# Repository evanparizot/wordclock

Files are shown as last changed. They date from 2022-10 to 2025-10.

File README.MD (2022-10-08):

# WordClock

This project is not a word clock based on the [wikipedia](https://en.wikipedia.org/wiki/Word_clock) definition, but rather just an aesthetic choice of representing time. Rather than showing something like a clock face or time in 12 hour / 24 hour format, a wordclock spells out the time using words. One of the more well known examples of wordclocks being produced is from the company [QLOCKTWO](https://qlocktwo.com/us?___from_store=de). Unfortunately, at it's retail price of $1,500+, they can be pretty expensive.

This project is to provide files for those who wish to build their own instead. It's been inspired by repositories such as [this](https://github.com/LikeClockwork/LargeWordClock) on providing both the pcb schematics, as well source code for anyone to look at. 

## Project Overview

Included in this repository are the graphics used to make up the clock face, the pcb schematics that outline the circuitry for the clock, as well the source code for the firmware used to run the wordclock. You can find each in their respective repostories. 

The pcb schematics were made using a mixture of Altium Designer and KiCad. The microcontroller is a variant of the STM32, with source code written in Rust. Each sub folder has further details on how to work with each of those components.

## Development Progress

Developmet of this project is ongoing and will be for some time. I will be keeping milestones in a Github project for the repository to track progress.

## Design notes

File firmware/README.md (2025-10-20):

# Overview

## Linux Usage

1. Run `./ocd.sh`
1. Run `cargo build`
1. Run `cargo run`

## Install Rust build target

```
rustup target add thumbv7em-none-eabihf
```

## Compiling
```
cargo build

cargo build --release

cargo build --release --features "mode-default"
```

## Start OpenOCD
```
openocd -s C:\OpenOCD\share\scripts -f interface/stlink-v2-1.cfg -f target/stm32f3x.cfg

openocd -f interface/stlink-v2-1.cfg -f target/stm32f3x.cfg
```

## Flashing Chip

OpenOCD in windows cmd
```
cd %TEMP%
openocd -s C:\share\scripts -f interface/stlink-v2-1.cfg -f target/stm32f3x.cfg
```

Start Debug session
```
cargo run --target thumbv7em-none-eabihf
```

Connect to OpenOCD and connect to f3
```
(gdb) target remote :3333
```

Flash program
```
(gdb) load
```
## Hardware Debugging
```
# Need debug file for this to be useful
cargo run

# Adds breakpoint at main
(gdb) break main 

# Continue to next breakpoint
(gdb) continue

# Step one line
(gdb) step

# Shows inner code
(gdb) disassemble /m

# Print variable value
(gdb) print x
(gdb) print &x

# Print all local variables
(gdb) info locals

# Reset microcontroller
(gdb) monitor reset halt

# Set variable
(gdb) set variable = 100

```

## sout
Can print things back to the debugging computer through the use of `iprintln!()`

```
itmdump -F -f itm.txt
```

## Release
```
cargo build --target thumbv7em-none-eabihf --release

cargo size --target thumbv7em-none-eabihf --bin led-roulette -- -A
```

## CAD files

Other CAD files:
schematics/enclosure/wordclock.FCStd

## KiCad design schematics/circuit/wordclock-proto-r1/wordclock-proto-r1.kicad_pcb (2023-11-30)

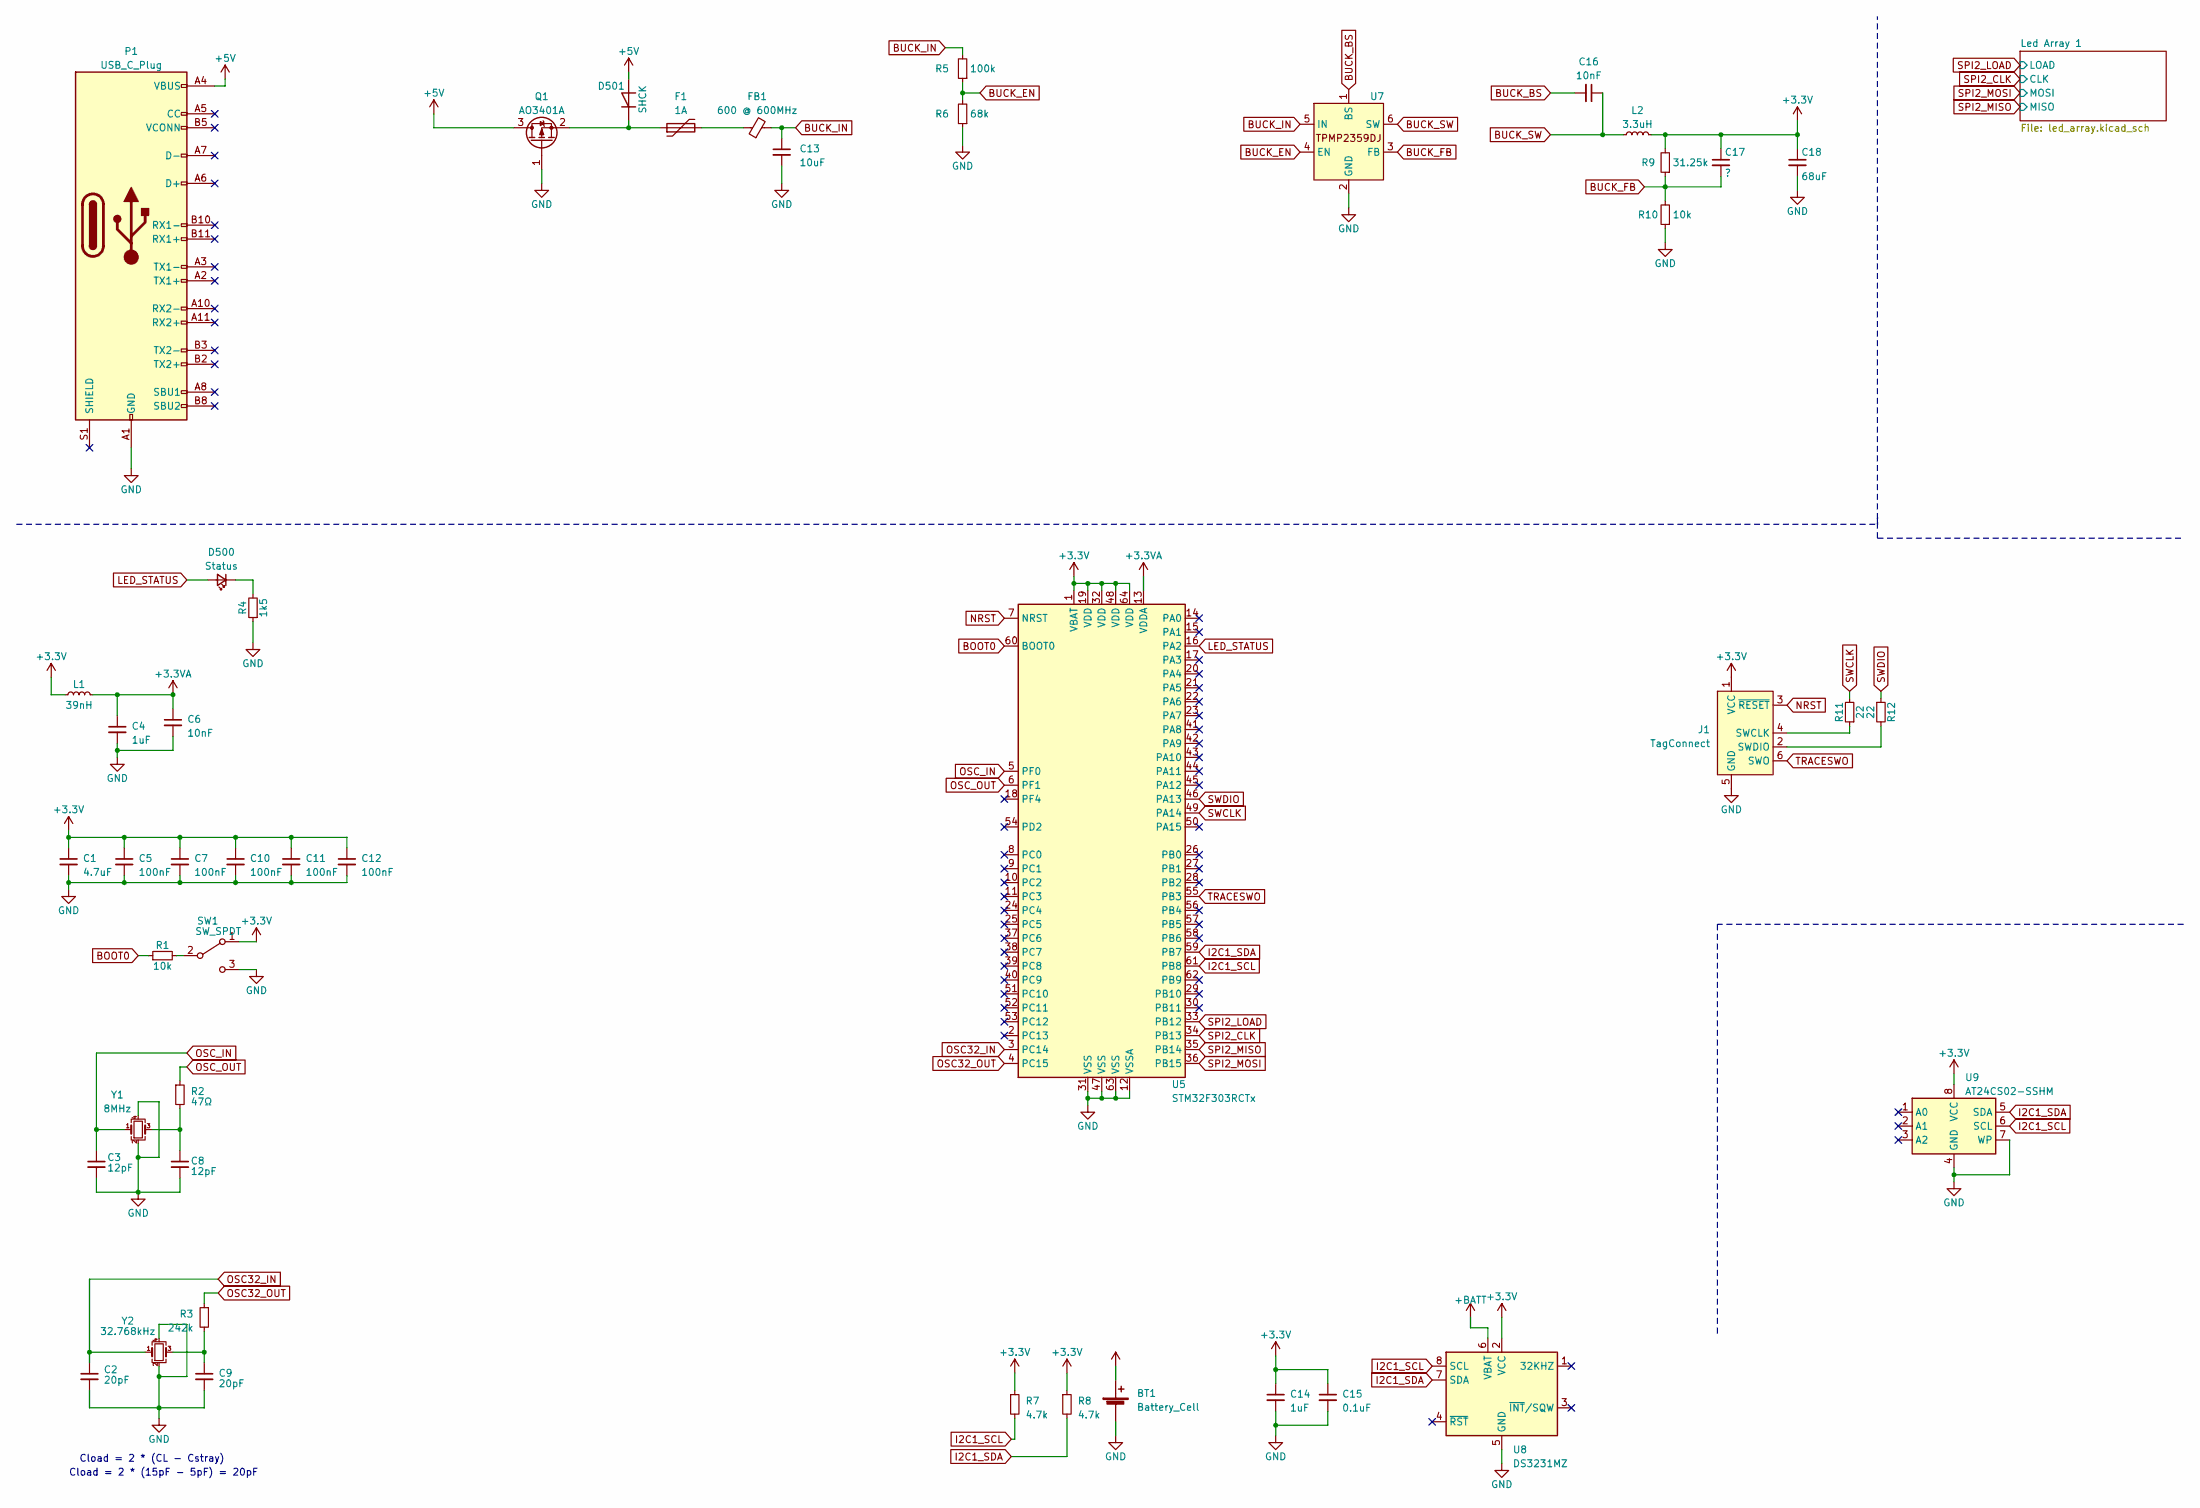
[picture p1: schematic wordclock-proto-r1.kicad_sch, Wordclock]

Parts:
BT1: Battery_Cell; BatteryHolder_Keystone_3002_1x2032
C1: 4.7uF; C_0603_1608Metric
C2, C9: 20pF; C_0402_1005Metric
C3, C8: 12pF; C_0402_1005Metric
C4, C14: 1uF; C_0402_1005Metric
C5, C7, C10, C11, C12: 100nF; C_0402_1005Metric
C6: 10nF; C_0402_1005Metric
C13: 10uF; C_0805_2012Metric
C15: 0.1uF; C_0402_1005Metric
C16: 10nF; C_0603_1608Metric
C17: ?; C_0603_1608Metric
C18: 68uF; C_0603_1608Metric
D500: Status; LED_0603_1608Metric
D501: SHCK; D_SOD-123
F1: 1A; Fuse_1206_3216Metric
FB1: 600 @ 600MHz; L_0805_2012Metric
J1: TagConnect; Tag-Connect_TC2030-IDC-FP_2x03_P1.27mm_Vertical
L1: 39nH; L_Sunlord_MWSA0518S
L2: 3.3uH; L_0402_1005Metric
P1: USB_C_Plug; USB_C_Receptacle_GCT_USB4115-03-C
Q1: AO3401A; SOT-23
R1: 10k; R_0603_1608Metric
R2: 47Ω; R_0402_1005Metric
R3: 242k; R_0402_1005Metric
R4: 1k5; R_0402_1005Metric
R5: 100k; R_0805_2012Metric
R6: 68k; R_0805_2012Metric
R7, R8: 4.7k; R_0402_1005Metric
R9: 31.25k; R_0805_2012Metric
R10: 10k; R_0805_2012Metric
R11, R12: 22; R_0603_1608Metric
SW1: SW_SPDT; SW_SPDT_PCM12
U5: STM32F303RCTx; LQFP-64_10x10mm_P0.5mm
U7: SOT-23-6
U8: DS3231MZ; SOIC-8_3.9x4.9mm_P1.27mm
U9: AT24CS02-SSHM; SOIC-8_3.9x4.9mm_P1.27mm
Y1: 8MHz; Crystal_SMD_3225-4Pin_3.2x2.5mm
Y2: 32.768kHz; Crystal_SMD_3225-4Pin_3.2x2.5mm

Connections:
+3.3V: C1.1, C5.1, C7.1, C10.1, C11.1, C12.1, C14.1, C15.1, C17.1, C18.1, J1.1 (VCC), L1.1, L2.2, R7.1, R8.1, R9.2, SW1.1 (A), U5.1 (VBAT), U5.19 (VDD), U5.32 (VDD), U5.48 (VDD), U5.64 (VDD), U8.2 (VCC), U9.8 (VCC); also elsewhere on the board
+3.3VA: C4.1, C6.1, L1.2, U5.13 (VDDA)
+5V: D501.2 (A), P1.A4 (VBUS), P1.A9 (VBUS), P1.B4 (VBUS), P1.B9 (VBUS), Q1.3 (D)
+BATT: BT1.1 (+), U8.6 (VBAT)
BOOT0: R1.1, U5.60 (BOOT0)
BUCK_BS: C16.2, U7.1 (BS)
BUCK_EN: R5.1, R6.2, U7.4 (EN)
BUCK_FB: C17.2, R9.1, R10.2, U7.3 (FB)
BUCK_IN: C13.1, FB1.2, R5.2, U7.5 (IN)
BUCK_SW: C16.1, L2.1, U7.6 (SW)
GND: BT1.2 (-), C1.2, C2.2, C3.2, C4.2, C5.2, C6.2, C7.2, C8.2, C9.2, C10.2, C11.2, C12.2, C13.2, C14.2, C15.2, C18.2, J1.5 (GND), P1.A1 (GND), P1.A12 (GND), P1.B1 (GND), P1.B12 (GND), Q1.1 (G), R4.1, R6.1, R10.1, SW1.3 (C), U5.12 (VSSA), U5.31 (VSS), U5.47 (VSS), U5.63 (VSS), U7.2 (GND), U8.5 (GND), U9.4 (GND), U9.7 (WP), Y1.2, Y1.4, Y2.2, Y2.4; also elsewhere on the board
I2C1_SCL: R7.2, U5.61 (PB8), U8.8 (SCL), U9.6 (SCL)
I2C1_SDA: R8.2, U5.59 (PB7), U8.7 (SDA), U9.5 (SDA)
LED_STATUS: D500.2 (A), U5.16 (PA2)
NRST: J1.3 (~RESET), U5.7 (NRST)
unnamed: C8.1, R2.2, Y1.3
unnamed: C9.1, R3.2, Y2.3
unnamed: D500.1 (K), R4.2
unnamed: D501.1 (K), F1.1, Q1.2 (S)
unnamed: F1.2, FB1.1
unnamed: J1.4 (SWCLK), R11.1
unnamed: J1.2 (SWDIO), R12.2
unnamed: R1.2, SW1.2 (B)
OSC32_IN: C2.1, U5.3 (PC14), Y2.1
OSC32_OUT: R3.1, U5.4 (PC15)
OSC_IN: C3.1, U5.5 (PF0), Y1.1
OSC_OUT: R2.1, U5.6 (PF1)
SPI2_CLK: U5.34 (PB13); also elsewhere on the board
SPI2_LOAD: U5.33 (PB12); also elsewhere on the board
SPI2_MISO: U5.35 (PB14); also elsewhere on the board
SPI2_MOSI: U5.36 (PB15); also elsewhere on the board
SWCLK: R11.2, U5.49 (PA14)
SWDIO: R12.1, U5.46 (PA13)
TRACESWO: J1.6 (SWO), U5.55 (PB3)

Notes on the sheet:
Cload = 2 * (15pF - 5pF) = 20pF
Cload = 2 * (CL - Cstray)

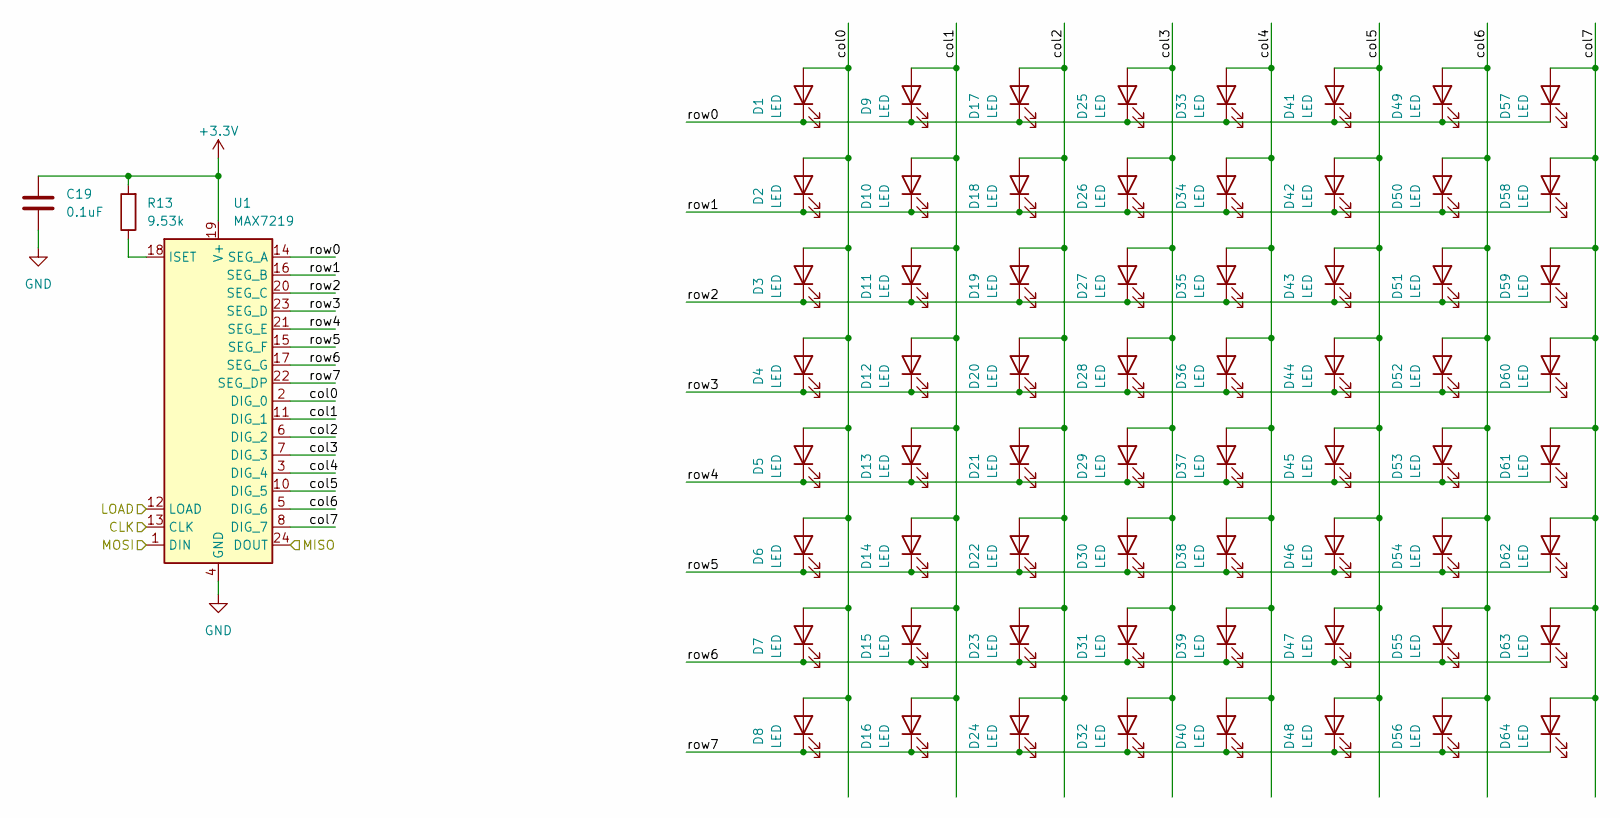
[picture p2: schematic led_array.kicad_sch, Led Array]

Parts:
C19: 0.1uF; C_0805_2012Metric
D1, D2, D3, D4, D5, D6, D7, D8, D9, D10, D11, D12, D13, D14, D15, D16, D17, D18, D19, D20, D21, D22, D23, D24, D25, D26, D27, D28, D29, D30, D31, D32, D33, D34, D35, D36, D37, D38, D39, D40, D41, D42, D43, D44, D45, D46, D47, D48, D49, D50, D51, D52, D53, D54, D55, D56, D57, D58, D59, D60, D61, D62, D63, D64: LED; LED_2010_5025Metric_Pad1.52x2.65mm_HandSolder
R13: 9.53k; R_0805_2012Metric
U1: MAX7219; SOIC-24W_7.5x15.4mm_P1.27mm

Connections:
+3.3V: C19.1, R13.2, U1.19 (V+); also elsewhere on the board
/Led Array 1/col0: D1.2 (A), D2.2 (A), D3.2 (A), D4.2 (A), D5.2 (A), D6.2 (A), D7.2 (A), D8.2 (A), U1.2 (DIG_0)
/Led Array 1/col1: D9.2 (A), D10.2 (A), D11.2 (A), D12.2 (A), D13.2 (A), D14.2 (A), D15.2 (A), D16.2 (A), U1.11 (DIG_1)
/Led Array 1/col2: D17.2 (A), D18.2 (A), D19.2 (A), D20.2 (A), D21.2 (A), D22.2 (A), D23.2 (A), D24.2 (A), U1.6 (DIG_2)
/Led Array 1/col3: D25.2 (A), D26.2 (A), D27.2 (A), D28.2 (A), D29.2 (A), D30.2 (A), D31.2 (A), D32.2 (A), U1.7 (DIG_3)
/Led Array 1/col4: D33.2 (A), D34.2 (A), D35.2 (A), D36.2 (A), D37.2 (A), D38.2 (A), D39.2 (A), D40.2 (A), U1.3 (DIG_4)
/Led Array 1/col5: D41.2 (A), D42.2 (A), D43.2 (A), D44.2 (A), D45.2 (A), D46.2 (A), D47.2 (A), D48.2 (A), U1.10 (DIG_5)
/Led Array 1/col6: D49.2 (A), D50.2 (A), D51.2 (A), D52.2 (A), D53.2 (A), D54.2 (A), D55.2 (A), D56.2 (A), U1.5 (DIG_6)
/Led Array 1/col7: D57.2 (A), D58.2 (A), D59.2 (A), D60.2 (A), D61.2 (A), D62.2 (A), D63.2 (A), D64.2 (A), U1.8 (DIG_7)
/Led Array 1/row0: D1.1 (K), D9.1 (K), D17.1 (K), D25.1 (K), D33.1 (K), D41.1 (K), D49.1 (K), D57.1 (K), U1.14 (SEG_A)
/Led Array 1/row1: D2.1 (K), D10.1 (K), D18.1 (K), D26.1 (K), D34.1 (K), D42.1 (K), D50.1 (K), D58.1 (K), U1.16 (SEG_B)
/Led Array 1/row2: D3.1 (K), D11.1 (K), D19.1 (K), D27.1 (K), D35.1 (K), D43.1 (K), D51.1 (K), D59.1 (K), U1.20 (SEG_C)
/Led Array 1/row3: D4.1 (K), D12.1 (K), D20.1 (K), D28.1 (K), D36.1 (K), D44.1 (K), D52.1 (K), D60.1 (K), U1.23 (SEG_D)
/Led Array 1/row4: D5.1 (K), D13.1 (K), D21.1 (K), D29.1 (K), D37.1 (K), D45.1 (K), D53.1 (K), D61.1 (K), U1.21 (SEG_E)
/Led Array 1/row5: D6.1 (K), D14.1 (K), D22.1 (K), D30.1 (K), D38.1 (K), D46.1 (K), D54.1 (K), D62.1 (K), U1.15 (SEG_F)
/Led Array 1/row6: D7.1 (K), D15.1 (K), D23.1 (K), D31.1 (K), D39.1 (K), D47.1 (K), D55.1 (K), D63.1 (K), U1.17 (SEG_G)
/Led Array 1/row7: D8.1 (K), D16.1 (K), D24.1 (K), D32.1 (K), D40.1 (K), D48.1 (K), D56.1 (K), D64.1 (K), U1.22 (SEG_DP)
GND: C19.2, U1.4 (GND), U1.9 (GND); also elsewhere on the board
unnamed: R13.1, U1.18 (ISET)
SPI2_CLK: U1.13 (CLK); also elsewhere on the board
SPI2_LOAD: U1.12 (LOAD); also elsewhere on the board
SPI2_MISO: U1.24 (DOUT); also elsewhere on the board
SPI2_MOSI: U1.1 (DIN); also elsewhere on the board

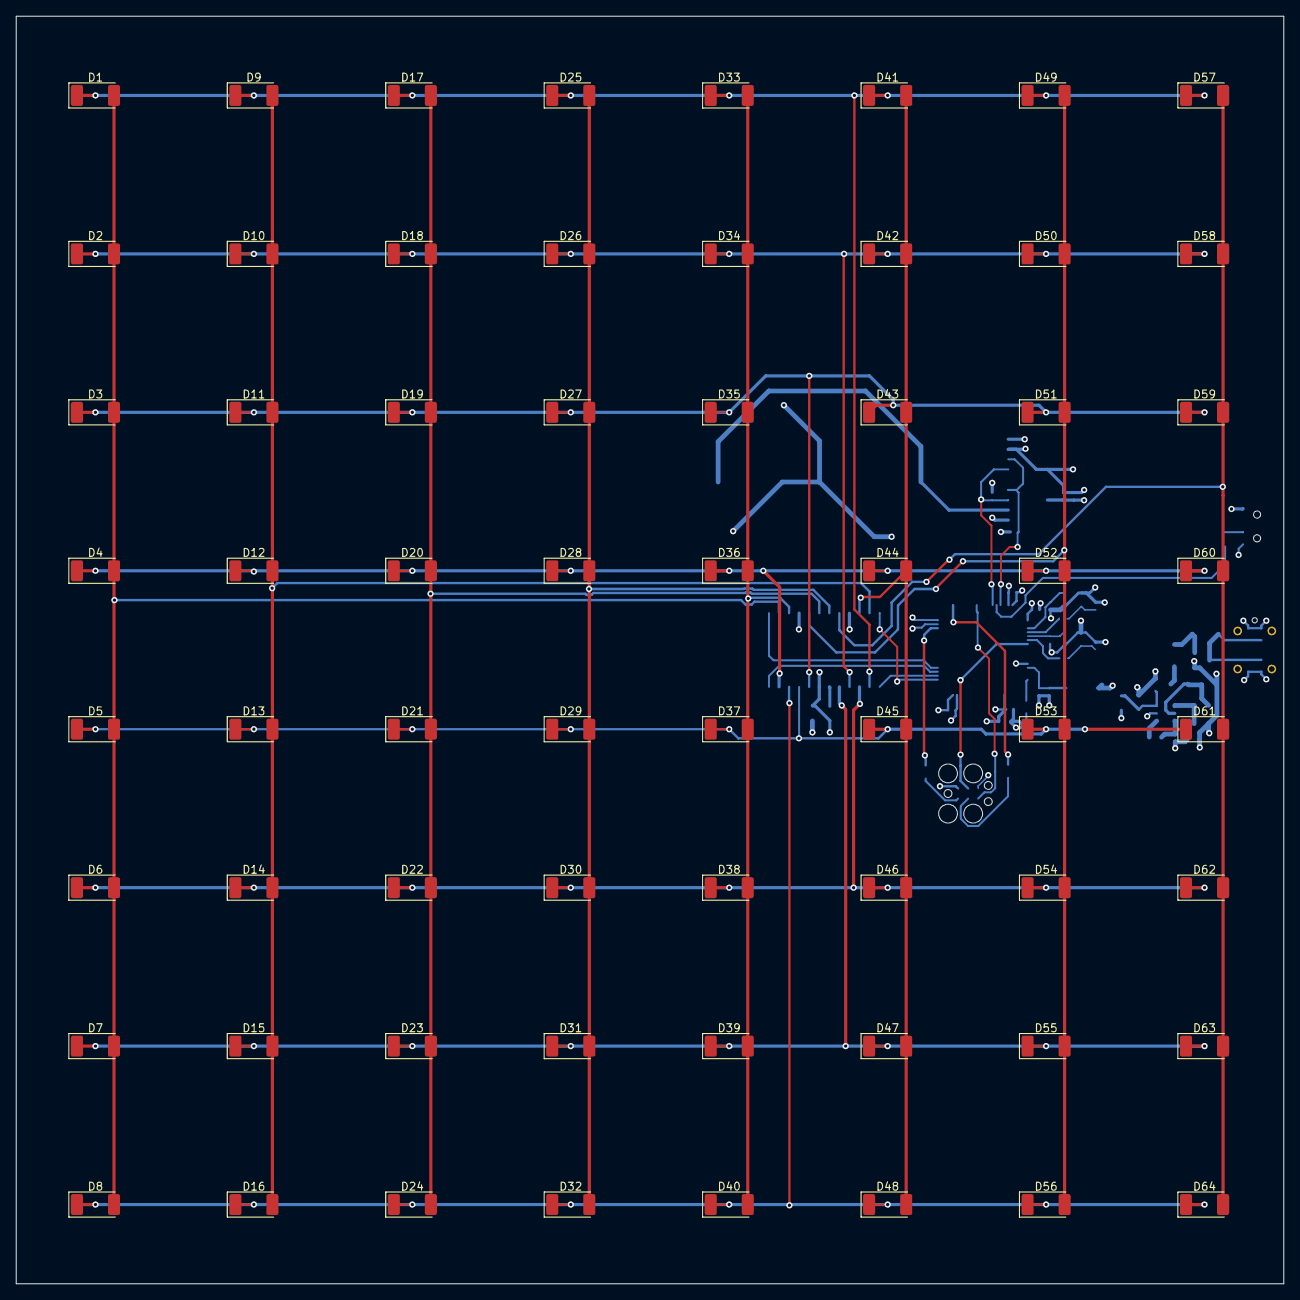
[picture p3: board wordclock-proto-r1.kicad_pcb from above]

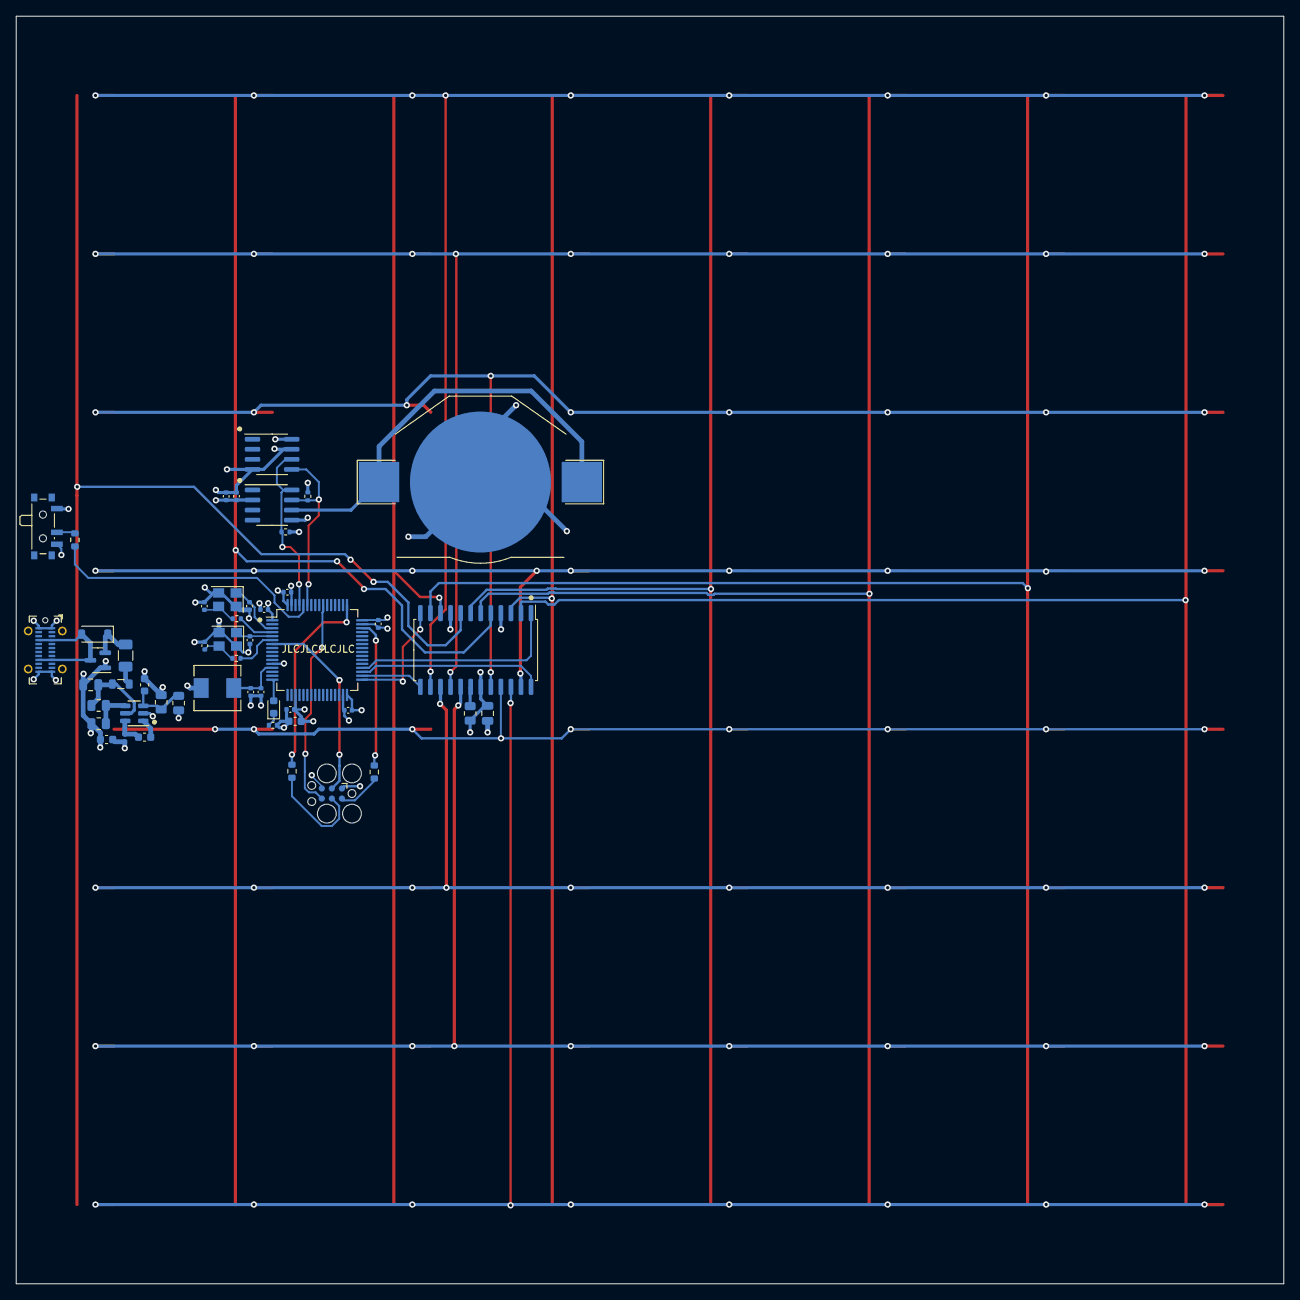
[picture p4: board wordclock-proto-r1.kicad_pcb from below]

Board: 4 copper layers, 160.0 x 160.0 mm, 114 parts (50 on the bottom side), 51 nets.

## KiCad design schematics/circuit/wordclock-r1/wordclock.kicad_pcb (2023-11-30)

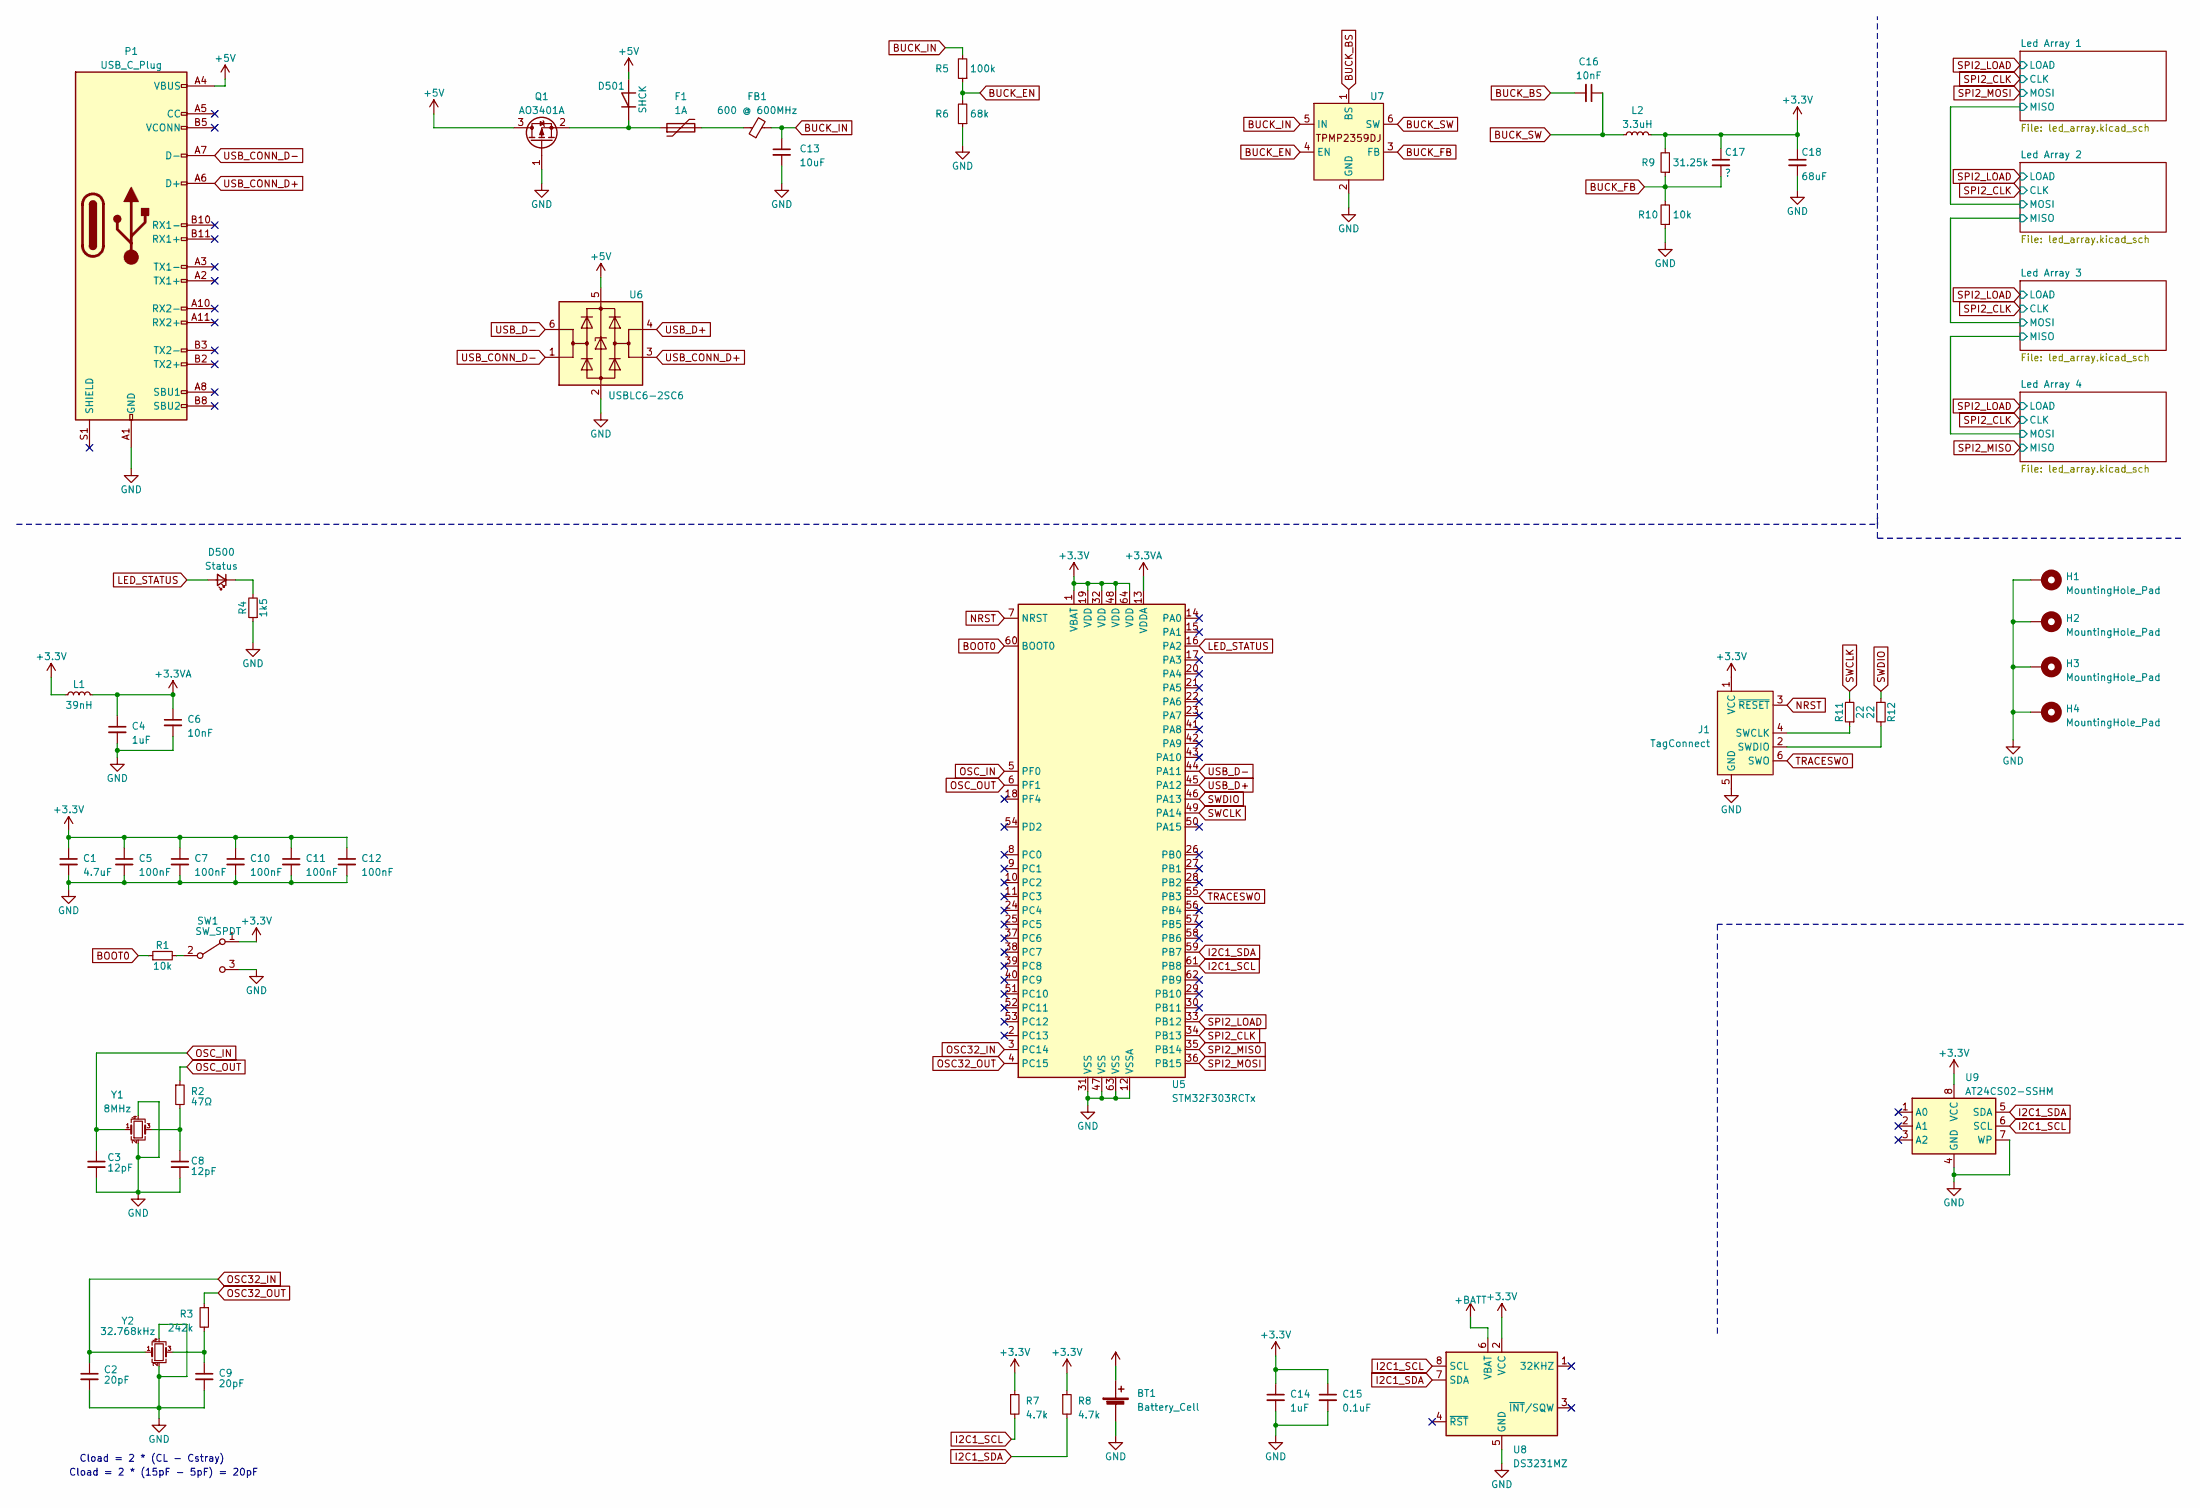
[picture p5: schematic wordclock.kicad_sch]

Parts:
BT1: Battery_Cell; BatteryHolder_Keystone_3002_1x2032
C1: 4.7uF; C_0603_1608Metric
C2, C9: 20pF; C_0402_1005Metric
C3, C8: 12pF; C_0402_1005Metric
C4, C14: 1uF; C_0402_1005Metric
C5, C7, C10, C11, C12: 100nF; C_0402_1005Metric
C6: 10nF; C_0402_1005Metric
C13: 10uF; C_0805_2012Metric
C15: 0.1uF; C_0402_1005Metric
C16: 10nF; C_0603_1608Metric
C17: ?; C_0603_1608Metric
C18: 68uF; C_0603_1608Metric
D500: Status; LED_0603_1608Metric
D501: SHCK; D_SOD-123
F1: 1A; Fuse_1206_3216Metric
FB1: 600 @ 600MHz; L_0805_2012Metric
H1, H2, H3, H4: MountingHole_Pad; MountingHole_4.3mm_M4_Pad_Via
J1: TagConnect; Tag-Connect_TC2030-IDC-FP_2x03_P1.27mm_Vertical
L1: 39nH; L_Sunlord_MWSA0518S
L2: 3.3uH; L_0402_1005Metric
P1: USB_C_Plug; USB_C_Receptacle_GCT_USB4115-03-C
Q1: AO3401A; SOT-23
R1: 10k; R_0603_1608Metric
R2: 47Ω; R_0402_1005Metric
R3: 242k; R_0402_1005Metric
R4: 1k5; R_0402_1005Metric
R5: 100k; R_0805_2012Metric
R6: 68k; R_0805_2012Metric
R7, R8: 4.7k; R_0402_1005Metric
R9: 31.25k; R_0805_2012Metric
R10: 10k; R_0805_2012Metric
R11, R12: 22; R_0603_1608Metric
SW1: SW_SPDT; SW_SPDT_PCM12
U5: STM32F303RCTx; LQFP-64_10x10mm_P0.5mm
U6: USBLC6-2SC6; SOT-23-6
U7: SOT-23-6
U8: DS3231MZ; SOIC-8_3.9x4.9mm_P1.27mm
U9: AT24CS02-SSHM; SOIC-8_3.9x4.9mm_P1.27mm
Y1: 8MHz; Crystal_SMD_3225-4Pin_3.2x2.5mm
Y2: 32.768kHz; Crystal_SMD_3225-4Pin_3.2x2.5mm

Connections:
+3.3V: C1.1, C5.1, C7.1, C10.1, C11.1, C12.1, C14.1, C15.1, C17.1, C18.1, J1.1 (VCC), L1.1, L2.2, R7.1, R8.1, R9.2, SW1.1 (A), U5.1 (VBAT), U5.19 (VDD), U5.32 (VDD), U5.48 (VDD), U5.64 (VDD), U8.2 (VCC), U9.8 (VCC); also elsewhere on the board
+3.3VA: C4.1, C6.1, L1.2, U5.13 (VDDA)
+5V: D501.2 (A), P1.A4 (VBUS), P1.A9 (VBUS), P1.B4 (VBUS), P1.B9 (VBUS), Q1.3 (D), U6.5 (VBUS)
+BATT: BT1.1 (+), U8.6 (VBAT)
BOOT0: R1.1, U5.60 (BOOT0)
BUCK_BS: C16.2, U7.1 (BS)
BUCK_EN: R5.1, R6.2, U7.4 (EN)
BUCK_FB: C17.2, R9.1, R10.2, U7.3 (FB)
BUCK_IN: C13.1, FB1.2, R5.2, U7.5 (IN)
BUCK_SW: C16.1, L2.1, U7.6 (SW)
GND: BT1.2 (-), C1.2, C2.2, C3.2, C4.2, C5.2, C6.2, C7.2, C8.2, C9.2, C10.2, C11.2, C12.2, C13.2, C14.2, C15.2, C18.2, H1.1, H2.1, H3.1, H4.1, J1.5 (GND), P1.A1 (GND), P1.A12 (GND), P1.B1 (GND), P1.B12 (GND), Q1.1 (G), R4.1, R6.1, R10.1, SW1.3 (C), U5.12 (VSSA), U5.31 (VSS), U5.47 (VSS), U5.63 (VSS), U6.2 (GND), U7.2 (GND), U8.5 (GND), U9.4 (GND), U9.7 (WP), Y1.2, Y1.4, Y2.2, Y2.4; also elsewhere on the board
I2C1_SCL: R7.2, U5.61 (PB8), U8.8 (SCL), U9.6 (SCL)
I2C1_SDA: R8.2, U5.59 (PB7), U8.7 (SDA), U9.5 (SDA)
LED_STATUS: D500.2 (A), U5.16 (PA2)
NRST: J1.3 (~RESET), U5.7 (NRST)
unnamed: C8.1, R2.2, Y1.3
unnamed: C9.1, R3.2, Y2.3
unnamed: D500.1 (K), R4.2
unnamed: D501.1 (K), F1.1, Q1.2 (S)
unnamed: F1.2, FB1.1
unnamed: J1.4 (SWCLK), R11.1
unnamed: J1.2 (SWDIO), R12.2
unnamed: R1.2, SW1.2 (B)
OSC32_IN: C2.1, U5.3 (PC14), Y2.1
OSC32_OUT: R3.1, U5.4 (PC15)
OSC_IN: C3.1, U5.5 (PF0), Y1.1
OSC_OUT: R2.1, U5.6 (PF1)
SPI2_CLK: U5.34 (PB13); also elsewhere on the board
SPI2_LOAD: U5.33 (PB12); also elsewhere on the board
SPI2_MISO: U5.35 (PB14); also elsewhere on the board
SPI2_MOSI: U5.36 (PB15); also elsewhere on the board
SWCLK: R11.2, U5.49 (PA14)
SWDIO: R12.1, U5.46 (PA13)
TRACESWO: J1.6 (SWO), U5.55 (PB3)
USB_CONN_D+: P1.A6 (D+), U6.3 (I/O2)
USB_CONN_D-: P1.A7 (D-), U6.1 (I/O1)
USB_D+: U5.45 (PA12), U6.4 (I/O2)
USB_D-: U5.44 (PA11), U6.6 (I/O1)

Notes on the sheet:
Cload = 2 * (15pF - 5pF) = 20pF
Cload = 2 * (CL - Cstray)

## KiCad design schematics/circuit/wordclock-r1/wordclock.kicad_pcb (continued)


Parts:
C19: 0.1uF; C_0805_2012Metric
D1, D2, D3, D4, D5, D6, D7, D8, D9, D10, D11, D12, D13, D14, D15, D16, D17, D18, D19, D20, D21, D22, D23, D24, D25, D26, D27, D28, D29, D30, D31, D32, D33, D34, D35, D36, D37, D38, D39, D40, D41, D42, D43, D44, D45, D46, D47, D48, D49, D50, D51, D52, D53, D54, D55, D56, D57, D58, D59, D60, D61, D62, D63, D64: LED; LED_2010_5025Metric_Pad1.52x2.65mm_HandSolder
R13: 9.53k; R_0805_2012Metric
U1: MAX7219; SOIC-24W_7.5x15.4mm_P1.27mm

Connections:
+3.3V: C19.1, R13.2, U1.19 (V+); also elsewhere on the board
/Led Array 1/MISO: U1.24 (DOUT); also elsewhere on the board
/Led Array 1/col0: D1.2 (A), D2.2 (A), D3.2 (A), D4.2 (A), D5.2 (A), D6.2 (A), D7.2 (A), D8.2 (A), U1.2 (DIG_0)
/Led Array 1/col1: D9.2 (A), D10.2 (A), D11.2 (A), D12.2 (A), D13.2 (A), D14.2 (A), D15.2 (A), D16.2 (A), U1.11 (DIG_1)
/Led Array 1/col2: D17.2 (A), D18.2 (A), D19.2 (A), D20.2 (A), D21.2 (A), D22.2 (A), D23.2 (A), D24.2 (A), U1.6 (DIG_2)
/Led Array 1/col3: D25.2 (A), D26.2 (A), D27.2 (A), D28.2 (A), D29.2 (A), D30.2 (A), D31.2 (A), D32.2 (A), U1.7 (DIG_3)
/Led Array 1/col4: D33.2 (A), D34.2 (A), D35.2 (A), D36.2 (A), D37.2 (A), D38.2 (A), D39.2 (A), D40.2 (A), U1.3 (DIG_4)
/Led Array 1/col5: D41.2 (A), D42.2 (A), D43.2 (A), D44.2 (A), D45.2 (A), D46.2 (A), D47.2 (A), D48.2 (A), U1.10 (DIG_5)
/Led Array 1/col6: D49.2 (A), D50.2 (A), D51.2 (A), D52.2 (A), D53.2 (A), D54.2 (A), D55.2 (A), D56.2 (A), U1.5 (DIG_6)
/Led Array 1/col7: D57.2 (A), D58.2 (A), D59.2 (A), D60.2 (A), D61.2 (A), D62.2 (A), D63.2 (A), D64.2 (A), U1.8 (DIG_7)
/Led Array 1/row0: D1.1 (K), D9.1 (K), D17.1 (K), D25.1 (K), D33.1 (K), D41.1 (K), D49.1 (K), D57.1 (K), U1.14 (SEG_A)
/Led Array 1/row1: D2.1 (K), D10.1 (K), D18.1 (K), D26.1 (K), D34.1 (K), D42.1 (K), D50.1 (K), D58.1 (K), U1.16 (SEG_B)
/Led Array 1/row2: D3.1 (K), D11.1 (K), D19.1 (K), D27.1 (K), D35.1 (K), D43.1 (K), D51.1 (K), D59.1 (K), U1.20 (SEG_C)
/Led Array 1/row3: D4.1 (K), D12.1 (K), D20.1 (K), D28.1 (K), D36.1 (K), D44.1 (K), D52.1 (K), D60.1 (K), U1.23 (SEG_D)
/Led Array 1/row4: D5.1 (K), D13.1 (K), D21.1 (K), D29.1 (K), D37.1 (K), D45.1 (K), D53.1 (K), D61.1 (K), U1.21 (SEG_E)
/Led Array 1/row5: D6.1 (K), D14.1 (K), D22.1 (K), D30.1 (K), D38.1 (K), D46.1 (K), D54.1 (K), D62.1 (K), U1.15 (SEG_F)
/Led Array 1/row6: D7.1 (K), D15.1 (K), D23.1 (K), D31.1 (K), D39.1 (K), D47.1 (K), D55.1 (K), D63.1 (K), U1.17 (SEG_G)
/Led Array 1/row7: D8.1 (K), D16.1 (K), D24.1 (K), D32.1 (K), D40.1 (K), D48.1 (K), D56.1 (K), D64.1 (K), U1.22 (SEG_DP)
GND: C19.2, U1.4 (GND), U1.9 (GND); also elsewhere on the board
unnamed: R13.1, U1.18 (ISET)
SPI2_CLK: U1.13 (CLK); also elsewhere on the board
SPI2_LOAD: U1.12 (LOAD); also elsewhere on the board
SPI2_MOSI: U1.1 (DIN); also elsewhere on the board

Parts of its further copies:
C20, C21, C22: 0.1uF; C_0805_2012Metric
D65, D66, D67, D68, D69, D70, D71, D72, D73, D74, D75, D76, D77, D78, D79, D80, D81, D82, D83, D84, D85, D86, D87, D88, D89, D90, D91, D92, D93, D94, D95, D96, D97, D98, D99, D100, D101, D102, D103, D104, D105, D106, D107, D108, D109, D110, D111, D112, D113, D114, D115, D116, D117, D118, D119, D120, D121, D122, D123, D124, D125, D126, D127, D128, D129, D130, D131, D132, D133, D134, D135, D136, D137, D138, D139, D140, D141, D142, D143, D144, D145, D146, D147, D148, D149, D150, D151, D152, D153, D154, D155, D156, D157, D158, D159, D160, D161, D162, D163, D164, D165, D166, D167, D168, D169, D170, D171, D172, D173, D174, D175, D176, D177, D178, D179, D180, D181, D182, D183, D184, D185, D186, D187, D188, D189, D190, D191, D192, D193, D194, D195, D196, D197, D198, D199, D200, D201, D202, D203, D204, D205, D206, D207, D208, D209, D210, D211, D212, D213, D214, D215, D216, D217, D218, D219, D220, D221, D222, D223, D224, D225, D226, D227, D228, D229, D230, D231, D232, D233, D234, D235, D236, D237, D238, D239, D240, D241, D242, D243, D244, D245, D246, D247, D248, D249, D250, D251, D252, D253, D254, D255, D256: LED; LED_2010_5025Metric_Pad1.52x2.65mm_HandSolder
R14, R15, R16: 9.53k; R_0805_2012Metric
U2, U3, U4: MAX7219; SOIC-24W_7.5x15.4mm_P1.27mm

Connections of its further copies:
+3.3V: C20.1, C21.1, C22.1, R14.2, R15.2, R16.2, U2.19 (V+), U3.19 (V+), U4.19 (V+); also elsewhere on the board
/Led Array 1/MISO: U2.1 (DIN); also elsewhere on the board
/Led Array 2/MISO: U2.24 (DOUT), U3.1 (DIN)
/Led Array 2/col0: D65.2 (A), D66.2 (A), D67.2 (A), D68.2 (A), D69.2 (A), D70.2 (A), D71.2 (A), D72.2 (A), U2.2 (DIG_0)
/Led Array 2/col1: D73.2 (A), D74.2 (A), D75.2 (A), D76.2 (A), D77.2 (A), D78.2 (A), D79.2 (A), D80.2 (A), U2.11 (DIG_1)
/Led Array 2/col2: D81.2 (A), D82.2 (A), D83.2 (A), D84.2 (A), D85.2 (A), D86.2 (A), D87.2 (A), D88.2 (A), U2.6 (DIG_2)
/Led Array 2/col3: D89.2 (A), D90.2 (A), D91.2 (A), D92.2 (A), D93.2 (A), D94.2 (A), D95.2 (A), D96.2 (A), U2.7 (DIG_3)
/Led Array 2/col4: D97.2 (A), D98.2 (A), D99.2 (A), D100.2 (A), D101.2 (A), D102.2 (A), D103.2 (A), D104.2 (A), U2.3 (DIG_4)
/Led Array 2/col5: D105.2 (A), D106.2 (A), D107.2 (A), D108.2 (A), D109.2 (A), D110.2 (A), D111.2 (A), D112.2 (A), U2.10 (DIG_5)
/Led Array 2/col6: D113.2 (A), D114.2 (A), D115.2 (A), D116.2 (A), D117.2 (A), D118.2 (A), D119.2 (A), D120.2 (A), U2.5 (DIG_6)
/Led Array 2/col7: D121.2 (A), D122.2 (A), D123.2 (A), D124.2 (A), D125.2 (A), D126.2 (A), D127.2 (A), D128.2 (A), U2.8 (DIG_7)
/Led Array 2/row0: D65.1 (K), D73.1 (K), D81.1 (K), D89.1 (K), D97.1 (K), D105.1 (K), D113.1 (K), D121.1 (K), U2.14 (SEG_A)
/Led Array 2/row1: D66.1 (K), D74.1 (K), D82.1 (K), D90.1 (K), D98.1 (K), D106.1 (K), D114.1 (K), D122.1 (K), U2.16 (SEG_B)
/Led Array 2/row2: D67.1 (K), D75.1 (K), D83.1 (K), D91.1 (K), D99.1 (K), D107.1 (K), D115.1 (K), D123.1 (K), U2.20 (SEG_C)
/Led Array 2/row3: D68.1 (K), D76.1 (K), D84.1 (K), D92.1 (K), D100.1 (K), D108.1 (K), D116.1 (K), D124.1 (K), U2.23 (SEG_D)
/Led Array 2/row4: D69.1 (K), D77.1 (K), D85.1 (K), D93.1 (K), D101.1 (K), D109.1 (K), D117.1 (K), D125.1 (K), U2.21 (SEG_E)
/Led Array 2/row5: D70.1 (K), D78.1 (K), D86.1 (K), D94.1 (K), D102.1 (K), D110.1 (K), D118.1 (K), D126.1 (K), U2.15 (SEG_F)
/Led Array 2/row6: D71.1 (K), D79.1 (K), D87.1 (K), D95.1 (K), D103.1 (K), D111.1 (K), D119.1 (K), D127.1 (K), U2.17 (SEG_G)
/Led Array 2/row7: D72.1 (K), D80.1 (K), D88.1 (K), D96.1 (K), D104.1 (K), D112.1 (K), D120.1 (K), D128.1 (K), U2.22 (SEG_DP)
/Led Array 3/MISO: U3.24 (DOUT), U4.1 (DIN)
/Led Array 3/col0: D129.2 (A), D130.2 (A), D131.2 (A), D132.2 (A), D133.2 (A), D134.2 (A), D135.2 (A), D136.2 (A), U3.2 (DIG_0)
/Led Array 3/col1: D137.2 (A), D138.2 (A), D139.2 (A), D140.2 (A), D141.2 (A), D142.2 (A), D143.2 (A), D144.2 (A), U3.11 (DIG_1)
/Led Array 3/col2: D145.2 (A), D146.2 (A), D147.2 (A), D148.2 (A), D149.2 (A), D150.2 (A), D151.2 (A), D152.2 (A), U3.6 (DIG_2)
/Led Array 3/col3: D153.2 (A), D154.2 (A), D155.2 (A), D156.2 (A), D157.2 (A), D158.2 (A), D159.2 (A), D160.2 (A), U3.7 (DIG_3)
/Led Array 3/col4: D161.2 (A), D162.2 (A), D163.2 (A), D164.2 (A), D165.2 (A), D166.2 (A), D167.2 (A), D168.2 (A), U3.3 (DIG_4)
/Led Array 3/col5: D169.2 (A), D170.2 (A), D171.2 (A), D172.2 (A), D173.2 (A), D174.2 (A), D175.2 (A), D176.2 (A), U3.10 (DIG_5)
/Led Array 3/col6: D177.2 (A), D178.2 (A), D179.2 (A), D180.2 (A), D181.2 (A), D182.2 (A), D183.2 (A), D184.2 (A), U3.5 (DIG_6)
/Led Array 3/col7: D185.2 (A), D186.2 (A), D187.2 (A), D188.2 (A), D189.2 (A), D190.2 (A), D191.2 (A), D192.2 (A), U3.8 (DIG_7)
/Led Array 3/row0: D129.1 (K), D137.1 (K), D145.1 (K), D153.1 (K), D161.1 (K), D169.1 (K), D177.1 (K), D185.1 (K), U3.14 (SEG_A)
/Led Array 3/row1: D130.1 (K), D138.1 (K), D146.1 (K), D154.1 (K), D162.1 (K), D170.1 (K), D178.1 (K), D186.1 (K), U3.16 (SEG_B)
/Led Array 3/row2: D131.1 (K), D139.1 (K), D147.1 (K), D155.1 (K), D163.1 (K), D171.1 (K), D179.1 (K), D187.1 (K), U3.20 (SEG_C)
/Led Array 3/row3: D132.1 (K), D140.1 (K), D148.1 (K), D156.1 (K), D164.1 (K), D172.1 (K), D180.1 (K), D188.1 (K), U3.23 (SEG_D)
/Led Array 3/row4: D133.1 (K), D141.1 (K), D149.1 (K), D157.1 (K), D165.1 (K), D173.1 (K), D181.1 (K), D189.1 (K), U3.21 (SEG_E)
/Led Array 3/row5: D134.1 (K), D142.1 (K), D150.1 (K), D158.1 (K), D166.1 (K), D174.1 (K), D182.1 (K), D190.1 (K), U3.15 (SEG_F)
/Led Array 3/row6: D135.1 (K), D143.1 (K), D151.1 (K), D159.1 (K), D167.1 (K), D175.1 (K), D183.1 (K), D191.1 (K), U3.17 (SEG_G)
/Led Array 3/row7: D136.1 (K), D144.1 (K), D152.1 (K), D160.1 (K), D168.1 (K), D176.1 (K), D184.1 (K), D192.1 (K), U3.22 (SEG_DP)
/Led Array 4/col0: D193.2 (A), D194.2 (A), D195.2 (A), D196.2 (A), D197.2 (A), D198.2 (A), D199.2 (A), D200.2 (A), U4.2 (DIG_0)
/Led Array 4/col1: D201.2 (A), D202.2 (A), D203.2 (A), D204.2 (A), D205.2 (A), D206.2 (A), D207.2 (A), D208.2 (A), U4.11 (DIG_1)
/Led Array 4/col2: D209.2 (A), D210.2 (A), D211.2 (A), D212.2 (A), D213.2 (A), D214.2 (A), D215.2 (A), D216.2 (A), U4.6 (DIG_2)
/Led Array 4/col3: D217.2 (A), D218.2 (A), D219.2 (A), D220.2 (A), D221.2 (A), D222.2 (A), D223.2 (A), D224.2 (A), U4.7 (DIG_3)
/Led Array 4/col4: D225.2 (A), D226.2 (A), D227.2 (A), D228.2 (A), D229.2 (A), D230.2 (A), D231.2 (A), D232.2 (A), U4.3 (DIG_4)
/Led Array 4/col5: D233.2 (A), D234.2 (A), D235.2 (A), D236.2 (A), D237.2 (A), D238.2 (A), D239.2 (A), D240.2 (A), U4.10 (DIG_5)
/Led Array 4/col6: D241.2 (A), D242.2 (A), D243.2 (A), D244.2 (A), D245.2 (A), D246.2 (A), D247.2 (A), D248.2 (A), U4.5 (DIG_6)
/Led Array 4/col7: D249.2 (A), D250.2 (A), D251.2 (A), D252.2 (A), D253.2 (A), D254.2 (A), D255.2 (A), D256.2 (A), U4.8 (DIG_7)
/Led Array 4/row0: D193.1 (K), D201.1 (K), D209.1 (K), D217.1 (K), D225.1 (K), D233.1 (K), D241.1 (K), D249.1 (K), U4.14 (SEG_A)
/Led Array 4/row1: D194.1 (K), D202.1 (K), D210.1 (K), D218.1 (K), D226.1 (K), D234.1 (K), D242.1 (K), D250.1 (K), U4.16 (SEG_B)
/Led Array 4/row2: D195.1 (K), D203.1 (K), D211.1 (K), D219.1 (K), D227.1 (K), D235.1 (K), D243.1 (K), D251.1 (K), U4.20 (SEG_C)
/Led Array 4/row3: D196.1 (K), D204.1 (K), D212.1 (K), D220.1 (K), D228.1 (K), D236.1 (K), D244.1 (K), D252.1 (K), U4.23 (SEG_D)
/Led Array 4/row4: D197.1 (K), D205.1 (K), D213.1 (K), D221.1 (K), D229.1 (K), D237.1 (K), D245.1 (K), D253.1 (K), U4.21 (SEG_E)
/Led Array 4/row5: D198.1 (K), D206.1 (K), D214.1 (K), D222.1 (K), D230.1 (K), D238.1 (K), D246.1 (K), D254.1 (K), U4.15 (SEG_F)
/Led Array 4/row6: D199.1 (K), D207.1 (K), D215.1 (K), D223.1 (K), D231.1 (K), D239.1 (K), D247.1 (K), D255.1 (K), U4.17 (SEG_G)
/Led Array 4/row7: D200.1 (K), D208.1 (K), D216.1 (K), D224.1 (K), D232.1 (K), D240.1 (K), D248.1 (K), D256.1 (K), U4.22 (SEG_DP)
GND: C20.2, C21.2, C22.2, U2.4 (GND), U2.9 (GND), U3.4 (GND), U3.9 (GND), U4.4 (GND), U4.9 (GND); also elsewhere on the board
unnamed: R14.1, U2.18 (ISET)
unnamed: R15.1, U3.18 (ISET)
unnamed: R16.1, U4.18 (ISET)
SPI2_CLK: U2.13 (CLK), U3.13 (CLK), U4.13 (CLK); also elsewhere on the board
SPI2_LOAD: U2.12 (LOAD), U3.12 (LOAD), U4.12 (LOAD); also elsewhere on the board
SPI2_MISO: U4.24 (DOUT); also elsewhere on the board

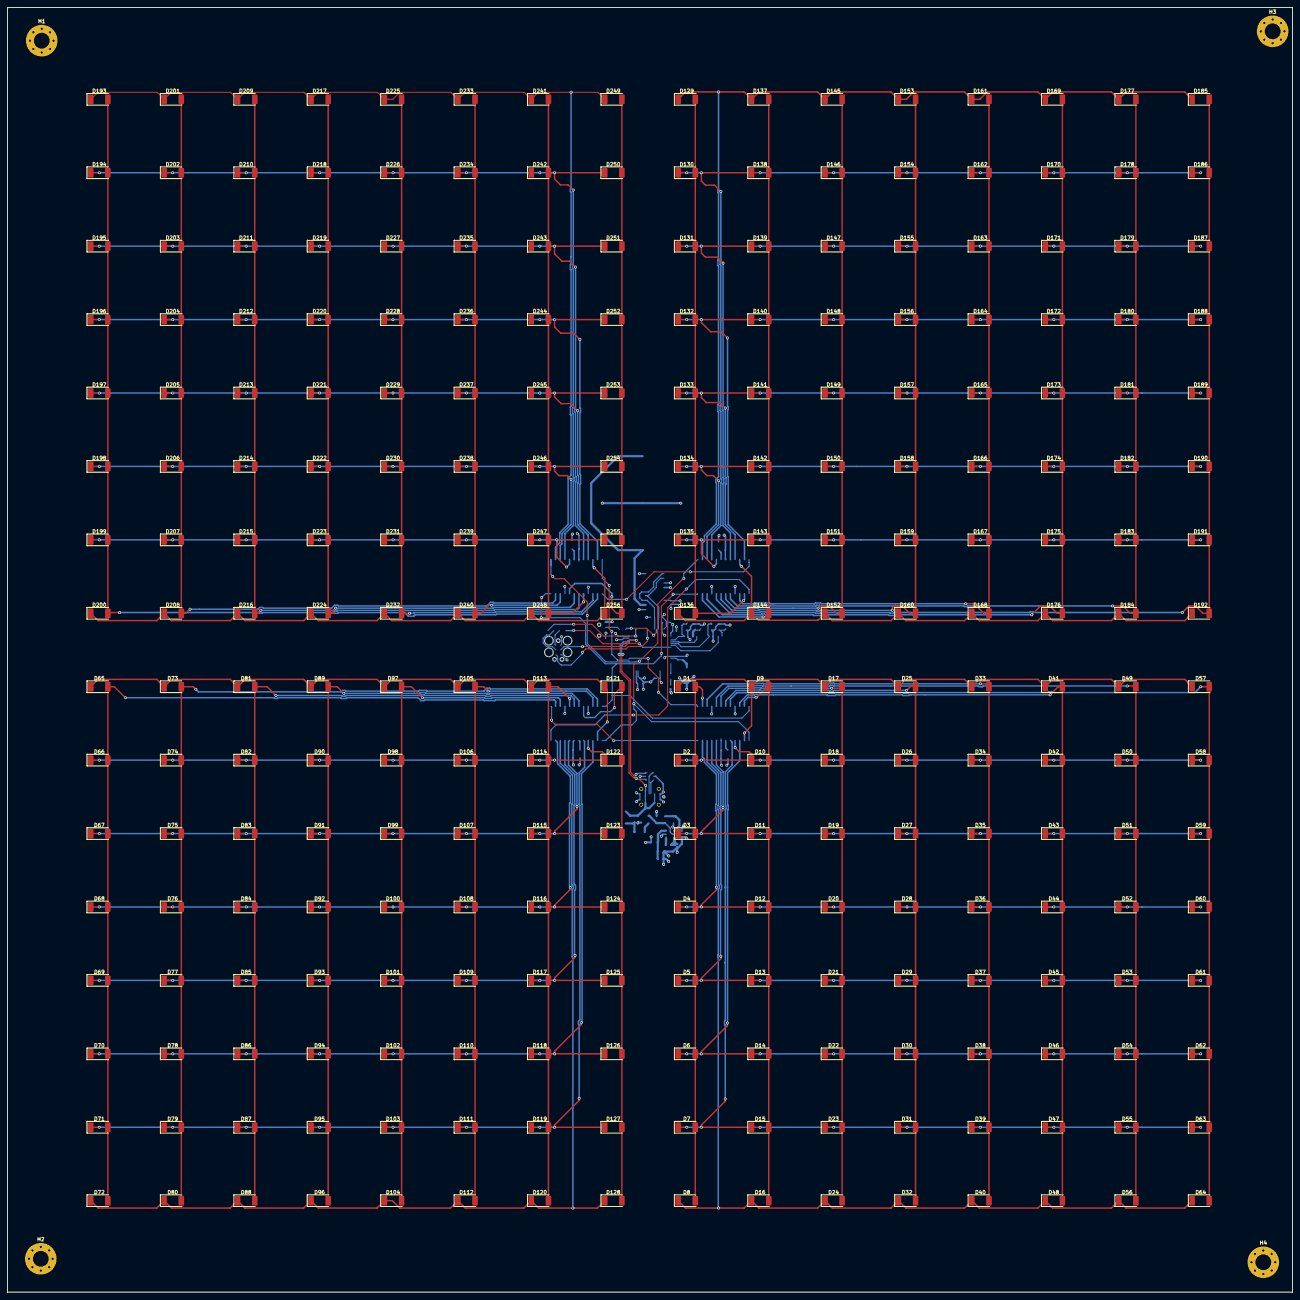
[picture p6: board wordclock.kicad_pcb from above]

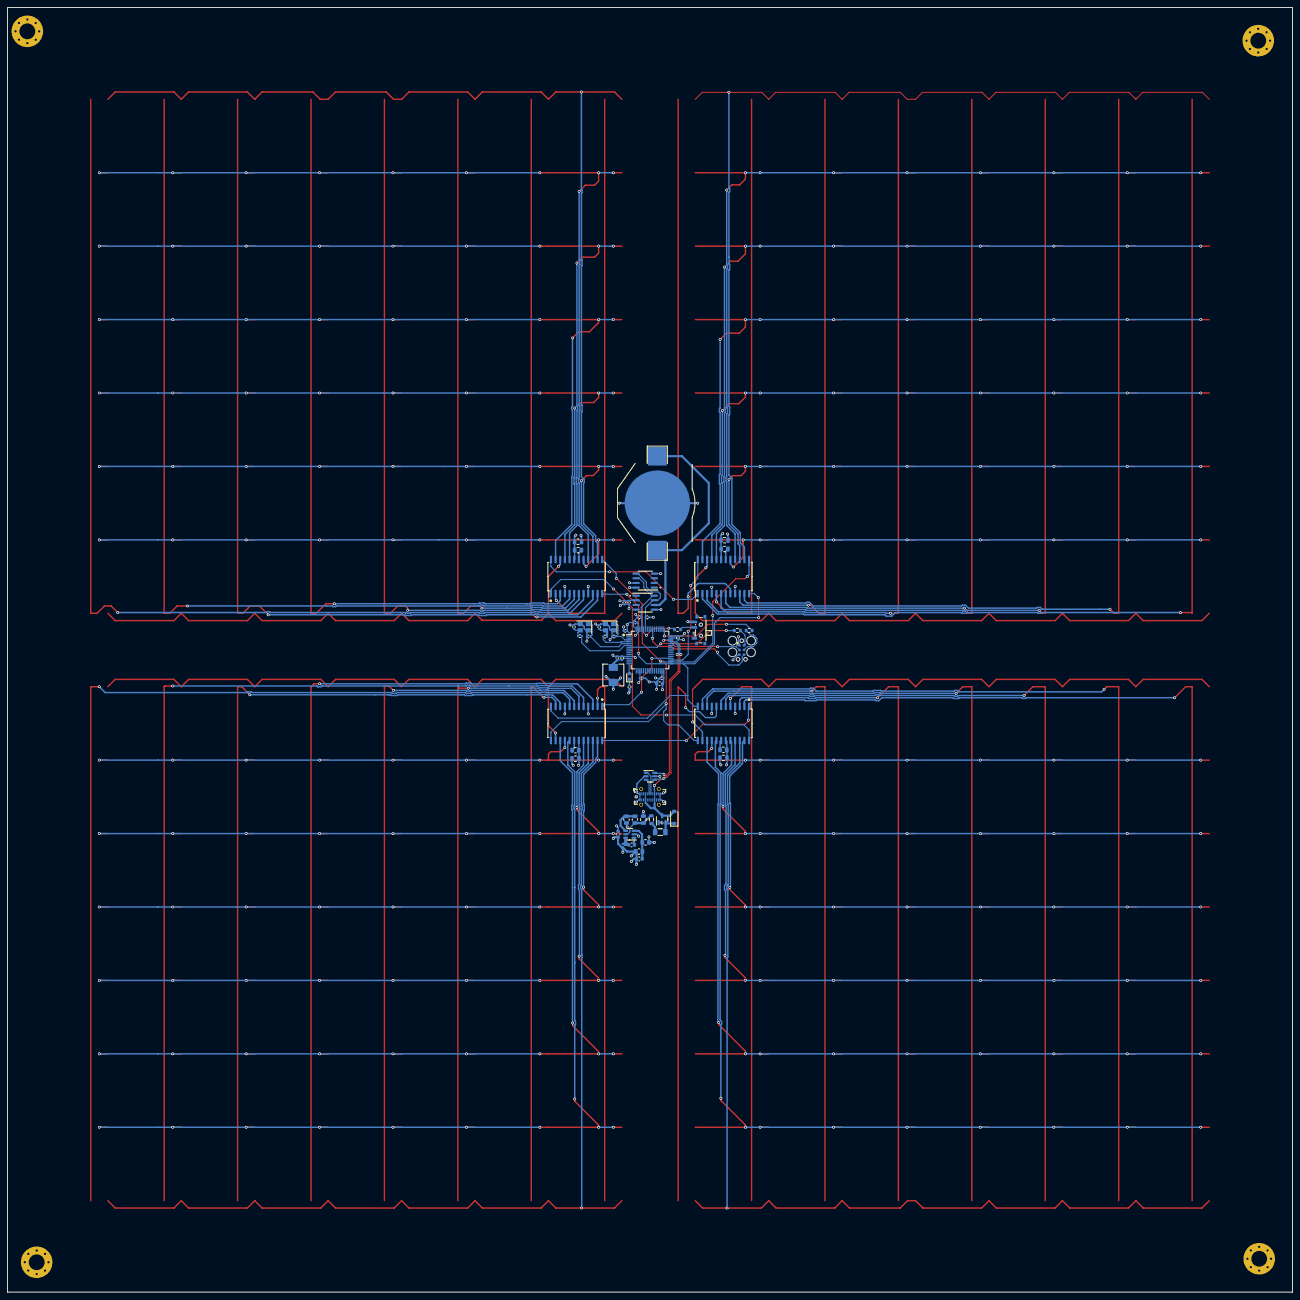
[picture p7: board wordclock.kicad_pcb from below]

Board: 4 copper layers, 350.0 x 349.9 mm, 320 parts (60 on the bottom side), 109 nets.

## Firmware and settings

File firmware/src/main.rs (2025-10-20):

#![no_main]
#![no_std]

// This needs to exist otherwise an error will be thrown
use panic_semihosting as _;
extern crate alloc;

mod clock;
mod config;
mod modes;
mod setup;
mod times;

use rtic_monotonics::systick::prelude::*;

systick_monotonic!(Mono, 1000);

use crate::times::TimeMode;
use alloc::boxed::Box;
use modes::{make_by_name, REGISTRY};

#[cfg(not(any(feature = "mode-default", feature = "mode-am")))]
compile_error!("Enable at least one `mode-*` feature.");

const BUILD_MODE: Option<&'static str> = option_env!("WORDCLOCK_MODE");

fn make_mode() -> Box<dyn TimeMode + Send> {
    if let Some(sel) = BUILD_MODE {
        if let Some(m) = make_by_name(sel) {
            return m;
        }
    }

    (REGISTRY[0].make)()
}

#[rtic::app(device = hal::pac, peripherals = true, dispatchers = [EXTI1])]
mod app {
    use crate::{
        clock::Clock,
        config::{DAY_INTENSITY, NIGHT_END_HOUR, NIGHT_INTENSITY, NIGHT_START_HOUR},
        Mono,
    };
    // use alloc::boxed::Box;
    // use cortex_m::peripheral::SYST;
    use rtic_monotonics::fugit::ExtU32;
    use rtic_monotonics::fugit::MillisDurationU32;
    use cortex_m_semihosting::hprintln;
    use hal::{
        gpio::{Input, PA0, PA2, PB2, PB3},
        // time::duration::Milliseconds,
    };
    use rtic_monotonics::Monotonic;

    const DEBOUNCE_MS: u32 = 200;
    const RENDER_PERIOD_MS: u32 = 500;

    const HOLD_MS: u32 = 700;
    const REPEAT_MS: u32 = 120;

    #[shared]
    struct Shared {
        clock: Clock,
        last_hour_press: Option<<Mono as rtic_monotonics::Monotonic>::Instant>,
        last_minute_press: Option<<Mono as rtic_monotonics::Monotonic>::Instant>,
        last_rendered_minute: Option<u32>,
        blink: bool,
        last_brightness: Option<u8>,

        last_hour_hold_start: Option<<Mono as rtic_monotonics::Monotonic>::Instant>,
        last_minute_hold_start: Option<<Mono as rtic_monotonics::Monotonic>::Instant>,
    }

    #[local]
    struct Local {
        hour_button: PA0<Input>,
        minute_button: PB3<Input>,
    }

    #[init]
    fn init(ctx: init::Context) -> (Shared, Local) {
        hprintln!("Initializing!");

        crate::setup::init_allocator();

        let mode = crate::make_mode();

        let (clock, hour_button, minute_button) = crate::setup::init(ctx.core, ctx.device, mode);

        let _ = render_tick::spawn();

        (
            Shared {
                clock,
                last_hour_press: None,
                last_minute_press: None,
                last_rendered_minute: None,
                blink: false,
                last_brightness: None,
                last_hour_hold_start: None,
                last_minute_hold_start: None,
            },
            Local {
                hour_button,
                minute_button,
            },
        )
    }

    #[idle]
    fn idle(_: idle::Context) -> ! {
        hprintln!("Time Idle!");

        loop {
            cortex_m::asm::wfi();
        }
    }

    #[task(priority = 1, shared = [clock, last_rendered_minute, blink, last_brightness])]
    async fn render_tick(mut ctx: render_tick::Context) {
        loop {
            // -------------------------------------------------------------
            // Brightness Checks

            let applied = ctx.shared.clock.lock(|c| {
                c.apply_time_based_brightness(
                    NIGHT_START_HOUR,
                    NIGHT_END_HOUR,
                    DAY_INTENSITY,
                    NIGHT_INTENSITY,
                )
            });

            let mut changed = false;
            ctx.shared.last_brightness.lock(|lb| {
                if lb.map(|old| old != applied).unwrap_or(true) {
                    *lb = Some(applied);
                    changed = true;
                }
            });

            // -------------------------------------------------------------
            // Render Checks

            // (1) Check current minute
            let minute_now = ctx.shared.clock.lock(|c| {
                let (_h, m, _s) = c.get_time();
                m as u32
            });

            let remainder = (minute_now % 5) as u8;
            let blink_on = ctx.shared.blink.lock(|b| { *b = !*b; *b });

            // (2) Decide if we need to render
            let mut need_render = false;
            ctx.shared.last_rendered_minute.lock(|last| {
                if last.map(|lm| lm != minute_now).unwrap_or(true) {
                    *last = Some(minute_now);
                    need_render = true;
                }
            });

            // (3) Render (only if necessary)
            if need_render {
                ctx.shared.clock.lock(|c| {
                    c.update_display_time();
                });
            } else {
                ctx.shared.clock.lock(|c| c.set_heartbeat(blink_on));
                // let on = ctx.shared.blink.lock(|b| {
                //     *b = !*b;
                //     *b
                // });
                // ctx.shared.clock.lock(|c| c.set_heartbeat(on));
            }

            let mut mask: u8 = 0;
            if remainder > 0 {
                for i in 0..(remainder - 1) {
                    mask |= 1 << i;
                }

                if blink_on {
                    mask |= 1 << (remainder - 1);
                }
            }

            set_minute_leds_mask(mask);

            // (Last) Re-arm next tick
            Mono::delay(MillisDurationU32::millis(RENDER_PERIOD_MS)).await;
        }
    }

    // https://docs.rs/stm32f3xx-hal/latest/stm32f3xx_hal/enum.interrupt.html
    #[task(binds = EXTI0, local = [hour_button], shared = [clock, last_hour_press, last_hour_hold_start])]
    fn update_hour(mut ctx: update_hour::Context) {
        ctx.local.hour_button.clear_interrupt();

        let now = Mono::now();
        let mut should_act = false;

        ctx.shared.last_hour_press.lock(|last| match *last {
            Some(prev) => {
                let elapsed = (now - prev).to_millis();
                if elapsed >= DEBOUNCE_MS {
                    *last = Some(now);
                    should_act = true;
                }
            }
            None => {
                *last = Some(now);
                should_act = true;
            }
        });

        if should_act {
            ctx.shared.clock.lock(|c| {
                c.add_hours(1);
                c.update_display_time();
            });

            if hour_button_pressed() {
                let mut spawn = false;
                ctx.shared.last_hour_hold_start.lock(|s| {
                    if s.is_none() {
                        *s = Some(Mono::now());
                        spawn = true;
                    }
                });
                if spawn {
                    let _ = hour_hold_repeat::spawn();
                }
            }
        }
    }

    #[task(binds = EXTI3, local = [minute_button], shared = [clock, last_minute_press, last_minute_hold_start])]
    fn update_minutes(mut ctx: update_minutes::Context) {
        ctx.local.minute_button.clear_interrupt();
        let now = Mono::now();
        let mut should_act = false;

        ctx.shared.last_minute_press.lock(|last| match *last {
            Some(prev) => {
                let elapsed = (now - prev).to_millis();
                if elapsed >= DEBOUNCE_MS {
                    *last = Some(now);
                    should_act = true;
                }
            }
            None => {
                *last = Some(now);
                should_act = true;
            }
        });

        if should_act {
            ctx.shared.clock.lock(|c| {
                c.add_minutes(1);
                c.update_display_time();
            });

            if minute_button_pressed() {
                let mut spawn = false;
                ctx.shared.last_minute_hold_start.lock(|s| {
                    if s.is_none() {
                        *s = Some(Mono::now());
                        spawn = true;
                    }
                });
                if spawn {
                    let _ = minute_hold_repeat::spawn();
                }
            }
        }
    }

    #[task(priority = 1, shared = [clock, last_minute_hold_start])]
    async fn minute_hold_repeat(mut ctx: minute_hold_repeat::Context) {
        loop {
            if !minute_button_pressed() {
                break; // released
            }
            let ready = ctx.shared.last_minute_hold_start.lock(|start| {
                start
                    .map(|t0| (Mono::now() - t0).to_millis() >= HOLD_MS)
                    .unwrap_or(false)
            });
            if ready {
                ctx.shared.clock.lock(|c| {
                    c.add_minutes(1);
                    c.update_display_time();
                });
                Mono::delay(REPEAT_MS.millis()).await;
            } else {
                Mono::delay(20u32.millis()).await; // poll until HOLD_MS reached
            }
        }
        // clear hold marker on release
        ctx.shared.last_minute_hold_start.lock(|s| *s = None);
    }

    #[task(priority = 1, shared = [clock, last_hour_hold_start])]
    async fn hour_hold_repeat(mut ctx: hour_hold_repeat::Context) {
        loop {
            if !hour_button_pressed() {
                break; // released
            }
            let ready = ctx.shared.last_hour_hold_start.lock(|start| {
                start
                    .map(|t0| (Mono::now() - t0).to_millis() >= HOLD_MS)
                    .unwrap_or(false)
            });
            if ready {
                ctx.shared.clock.lock(|c| {
                    c.add_hours(1);
                    c.update_display_time();
                });
                Mono::delay(REPEAT_MS.millis()).await;
            } else {
                Mono::delay(20u32.millis()).await;
            }
        }
        ctx.shared.last_hour_hold_start.lock(|s| *s = None);
    }

    #[inline]
    fn minute_button_pressed() -> bool {
        unsafe { (*hal::pac::GPIOB::ptr()).idr.read().idr3().bit_is_clear() }
    }

    #[inline]
    fn hour_button_pressed() -> bool {
        unsafe { (*hal::pac::GPIOA::ptr()).idr.read().idr0().bit_is_clear() }
    }

    const MIN_LED_PORT: *const hal::pac::gpioa::RegisterBlock = hal::pac::GPIOA::ptr();
    const MIN_LED_PINS: [u8; 4] = [1,2,3,4];

    #[inline]
    fn set_led_pa(pin: u8, on: bool) {
        unsafe {
            let gpioa = &*MIN_LED_PORT;
            if on {
                gpioa.bsrr.write(|w| w.bits(1u32 << pin));
            } else {
                gpioa.bsrr.write(|w| w.bits(1u32 << (pin + 16)));
            }
        }
    }

    #[inline]
    fn set_minute_leds_mask(mask: u8) {
        for (i, &pin) in MIN_LED_PINS.iter().enumerate() {
            let on = (mask >> i) & 1 == 1;
            set_led_pa(pin, on);
        }
    }
}

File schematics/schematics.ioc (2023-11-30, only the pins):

Mcu.UserName=STM32F303RCTx
PA11.Signal=USB_DM
PA12.Signal=USB_DP
PA13.Signal=SYS_JTMS-SWDIO
PA14.Signal=SYS_JTCK-SWCLK
PB13.Signal=SPI2_SCK
PB14.Signal=SPI2_MISO
PB15.Signal=SPI2_MOSI
PB3.Signal=SYS_JTDO-TRACESWO
PC14-OSC32_IN.Signal=RCC_OSC32_IN
PC15-OSC32_OUT.Signal=RCC_OSC32_OUT
PF0-OSC_IN.Signal=RCC_OSC_IN
PF1-OSC_OUT.Signal=RCC_OSC_OUT

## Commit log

2020-03-14 Move files to repository
    [14.22x14.22.PcbDoc, 14120x14120.PcbDoc, 14x14.PcbDoc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]
2020-03-17 Restructure project layout
    [14.22x14.22.PcbDoc, 14120x14120.PcbDoc, 14x14.PcbDoc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]
2020-03-17 Update BOM
    [BOM.xlsx]
2021-05-14 Add initial stm32 source files
2021-05-16 Update github pages and remove old files
    [14.22x14.22.PcbDoc, 14120x14120.PcbDoc, 14x14.PcbDoc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]
2022-10-08 Initial commit of kicad schematics files
    [wordclock-0.1.kicad_pcb, wordclock-0.1.kicad_sch, wordclock.kicad_pcb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]
2022-10-10 Define basic led arrays and main processor circuit
    [led_array.kicad_sch, wordclock-0.1.kicad_pcb, wordclock-0.1.kicad_sch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]
2023-02-25 Add stm32 power schematic datasheet
2023-02-27 Add initial GPIO initialization logic for SPI
2023-02-27 Add i2c initialization for ds3231 RTC
2023-04-14 RTIC and Configs (#3)
    * Define initial times config
    * Finish defining words, schematic updates
    * Change mode selection passing
    * change to rtic
    [led_array.kicad_sch, wordclock.kicad_pcb, wordclock.kicad_sch]
2023-11-30 PCB 0.1 Changes (#4)
    * Initial 16x16 wordclock layout
    * Change tracked files
    * Initial pcb layout
    * Add prototype board project
    * more pcb changes
    [led_array.kicad_sch, wordclock-proto-r1.kicad_pcb, wordclock-proto-r1.kicad_sch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]
2023-12-02 Implement button interrupts for hours, minutes (#5)
    * Reorganize timing
    * Define button interrupt
    * More timing changes
    * Initial implementation of time adjustment
    * Implement hour and minute buttons
    Use EXTI0 and EXTI3 interrupts to Implement
    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
2025-10-20 Implement several features for rendering and button holds (#6)
    * Switch libraries for interrupt handling
    * Implement improved display refresh functionality
    * Implement heartbeat feature
    * Implement auto-diming feature based on time
    * Add a more dynamic mode selection upon compile time
    * Implement minute leds and blink functionality
